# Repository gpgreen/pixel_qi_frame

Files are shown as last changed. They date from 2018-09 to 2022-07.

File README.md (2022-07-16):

# Pixel Qi Frame

3D printed frame for [Pixel Qi](https://www.adafruit.com/product/1303)
LCD panel. Includes adafruit hdmi [LVDS display driver
board](https://cdn-shop.adafruit.com/datasheets/PCB800099.pdf).  The
frame was modeled in OpenScad and is fully parametric. Conceivably it
can accomodate other types of LCD panels, with proper adjustment of
the parameters.

## OpenScad main file
display_frame.scad

## Included files
1. frameconfig.scad
2. button.scad
3. frame.scad
4. graphics_box.scad

## Pictures of printed frame

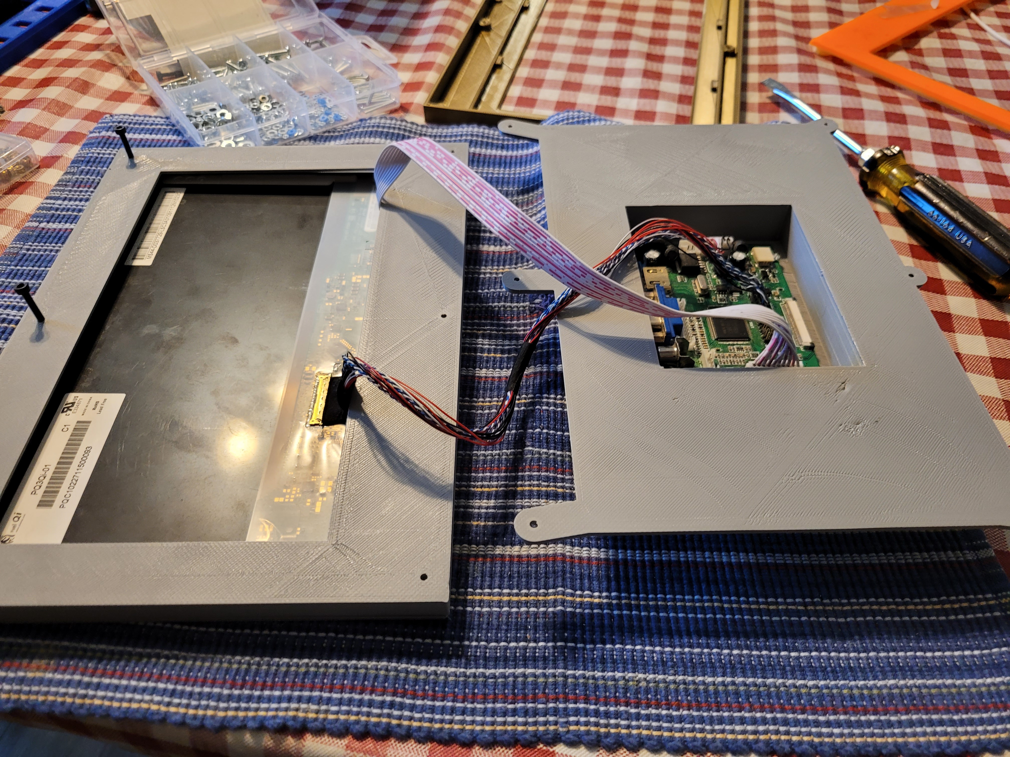
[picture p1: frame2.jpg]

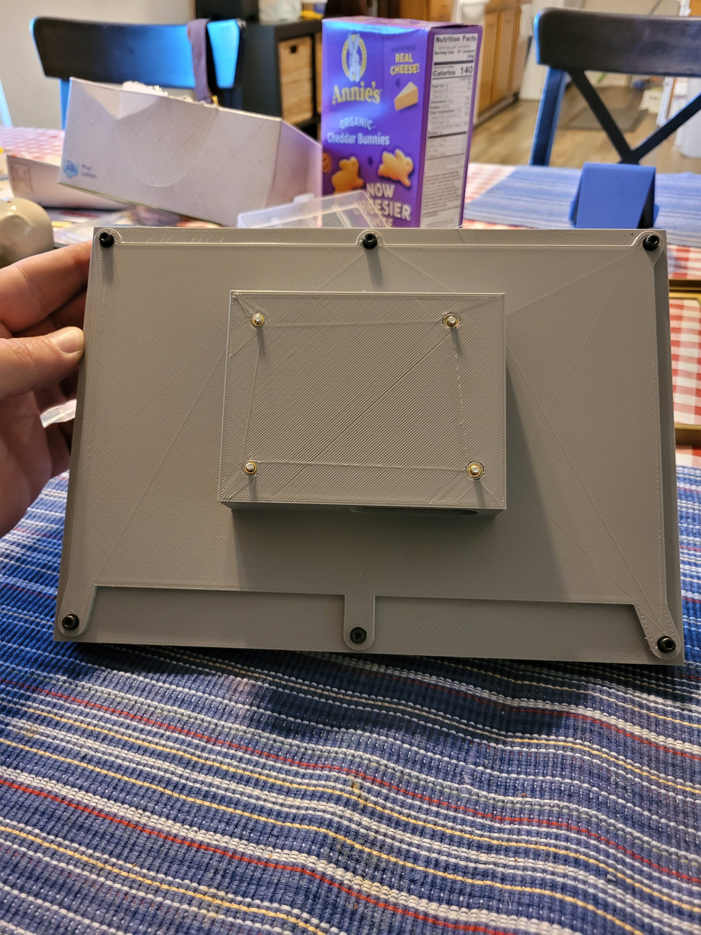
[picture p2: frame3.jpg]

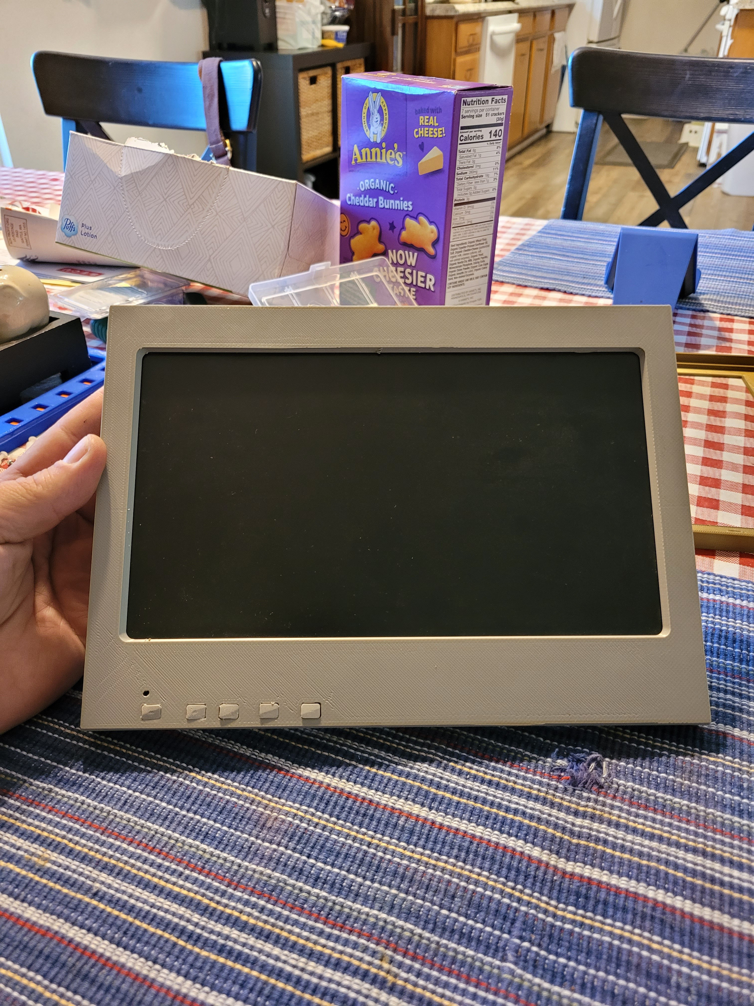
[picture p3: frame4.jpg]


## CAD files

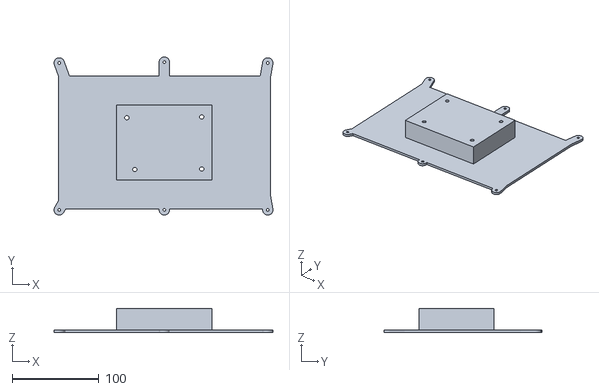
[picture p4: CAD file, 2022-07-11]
graphics_box.stl
252.0 x 182.0 x 28.0

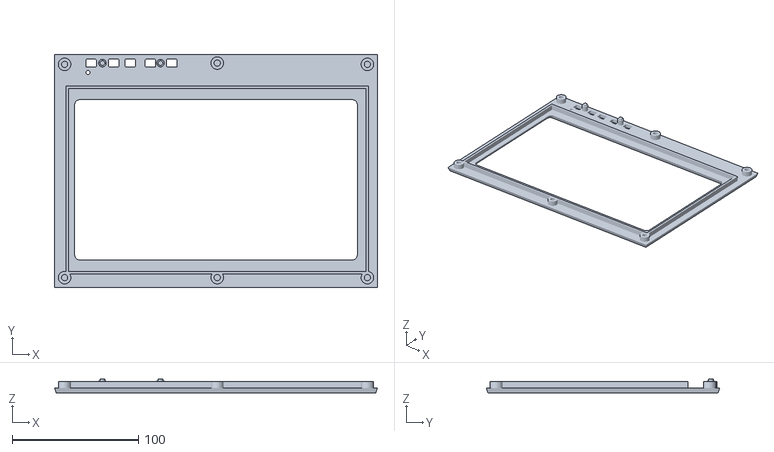
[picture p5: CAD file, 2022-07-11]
front_frame.stl
256.0 x 185.0 x 11.0

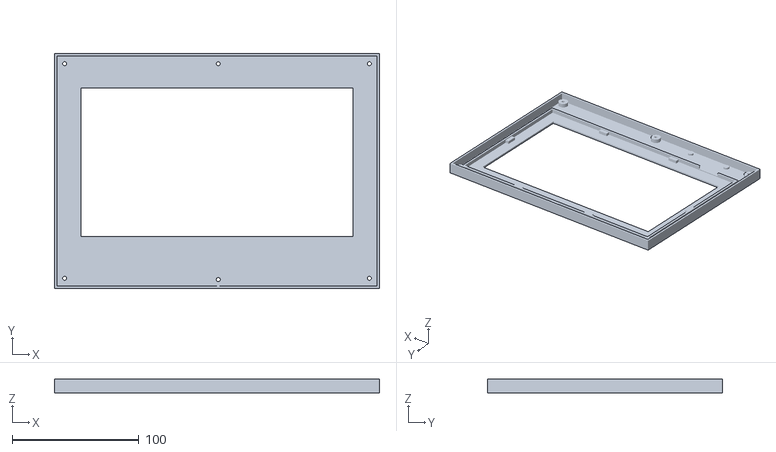
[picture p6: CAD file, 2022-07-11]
back_frame.stl
256.0 x 185.0 x 11.0

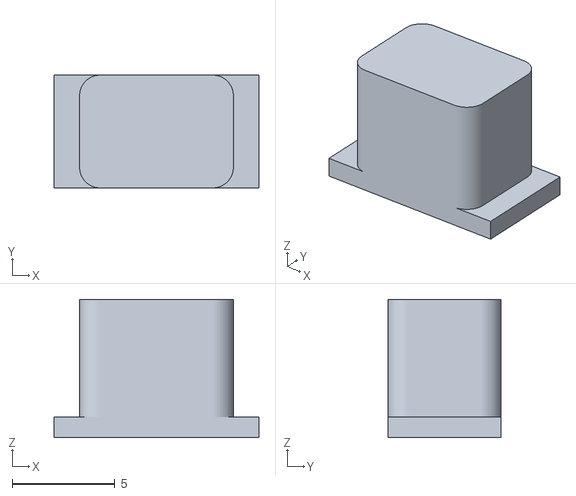
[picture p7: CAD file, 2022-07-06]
bot_button.stl
10.0 x 5.50 x 6.75

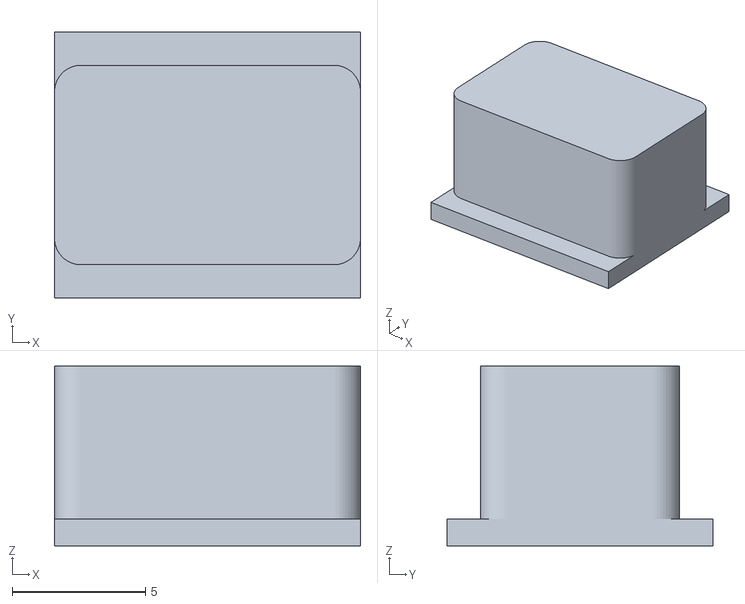
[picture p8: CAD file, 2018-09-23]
side_button.stl
11.5 x 10.0 x 6.75

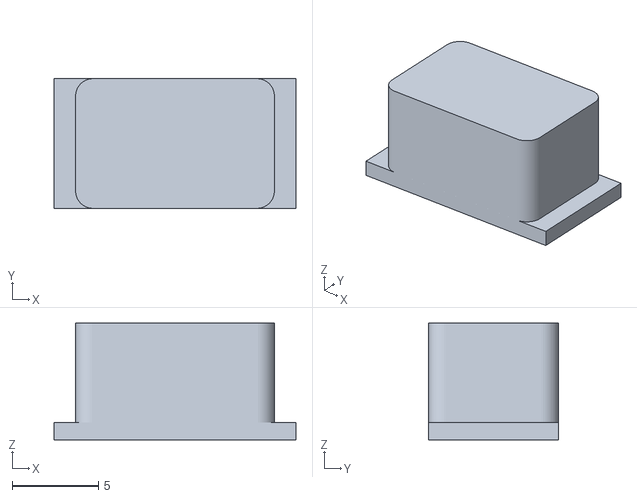
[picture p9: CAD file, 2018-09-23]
bottom_button.stl
14.0 x 7.50 x 6.75

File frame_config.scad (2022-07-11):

// Display for Pixel Qi lcd panel
// Copyright 2022 Greg Green
//
// frame_config.scad

// configurations
have_side_buttons=0;
have_bottom_buttons=1;
have_led_hole=1;
have_connector_holes=0;
have_display_buttons=1;
show_pcbs=1;

// display
display_width=234;
display_height=143;
// distances in from outside to viewing surface of display
display_top_bezel=8;
display_bottom_bezel=8;
display_left_bezel=4;
display_right_bezel=6;
// thickness of panel
display_thickness=6;

// flange inside frame
flange_height=5;
flange_gap=1;
flange_width=2;

// faceplate
faceplate_inset=2;
faceplate_lside_width=(have_side_buttons==1)? 22 : 12;
faceplate_rside_width=(have_side_buttons==1)? 20 : 10;
faceplate_top_width=14;
faceplate_bottom_width=(have_bottom_buttons==1)? 28 : 10;
faceplate_thickness=4;

// backframe
backframe_thickness=11;
backframe_center_thickness=2;
backframe_inset=5;

// side button placement
side_button_y_offsets = [-48, -24, 0, 24, 48];
side_button_pcb_offsets = [60,36,12,-12,-36,-60];

// bottom button placement
bottom_button_x_offsets = [-100, -82, -69, -53, -36];
bottom_button_pcb_offsets = [-91, -45];
bottom_connector_x = -20;

button_width=6;
button_height=4;
button_thickness=faceplate_thickness+2;
button_radius=1;
// center of button offset from outer frame edge
button_bottom_offset=5;
// inner edge of button offset from inner frame edge
button_side_offset=5;

// lcd panel pcb bosses
pcb_boss_radius=1.9;
pcb_thickness=1.5;

button_boss_radius=3;
button_boss_height=5.5;

backframe_boss_radius=3;
backframe_boss_height=backframe_thickness-pcb_thickness-button_boss_height;

// frame holes
frame_hole_radius = 1.6;
frame_hole_insert_radius = 2.5;
frame_boss_radius = 5;

// led coord
led_placement = [-102.5,7.5];
led_radius = 1.6;

// graphics board
graphics_box_height = 28;
graphics_box_thickness = 3;
graphics_pcb_offset = 10;

// graphics board pcb constants
graphics_pcb_width = 90;
graphics_pcb_height = 66;
graphics_pcb_thickness = 1.5;

graphics_pcb_hole_radius = 1.6;
graphics_pcb_insert_radius = 2.5;
graphics_pcb_coords = [
     [11,2], [88,2.5], [88,62.5], [1.8,61.5]
];

graphics_pcb_boss_height = 5;
graphics_pcb_boss_radius = 4;

//////////////////////////////////////////////////////////////////////////////////////////////////////////////
// derived variables
//////////////////////////////////////////////////////////////////////////////////////////////////////////////

// Vector of display corners
display_corners = [
    [-display_width/2-faceplate_lside_width,-display_height/2-faceplate_bottom_width,0],
    [-display_width/2-faceplate_lside_width,display_height/2+faceplate_top_width,0],
    [display_width/2+faceplate_rside_width,display_height/2+faceplate_top_width,0],
    [display_width/2+faceplate_rside_width,-display_height/2-faceplate_bottom_width,0]
];

// center lines of buttons
center_left_button_x = -display_width/2-faceplate_lside_width+button_side_offset+button_width/2;
center_right_button_x = display_width/2+faceplate_lside_width-button_side_offset-button_width/2;
center_bottom_button_y = -display_height/2-faceplate_bottom_width+button_bottom_offset+button_height/2;

// vector of frame bolt hole centers
bolt_offset = frame_boss_radius+3; // how far to offset from edge of display
bolt_displ = display_corners + [
     [bolt_offset, bolt_offset],
     [bolt_offset,-bolt_offset],
     [-bolt_offset,-bolt_offset],
     [-bolt_offset,bolt_offset]
];
bolt_hole_centers = concat(bolt_displ, [[0, bolt_displ[2].y]], [[0, center_bottom_button_y]]);

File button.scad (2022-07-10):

// Display from for Pixel Qi lcd panel
// Copyright 2022 Greg Green
//
// button.scad

include <frame_config.scad>

module button_top() {
    minkowski() {
        cube([button_width-button_radius*.5,
        button_height-button_radius*.5,
        button_thickness-2],
        center=true);
        cylinder(r=button_radius, h=1, $fn=64);
    }
}

module button_bottom() {
    linear_extrude(height=1, center=true) {
        polygon(points=[
	[-1, -.75],
	[button_width+3,-.75],
	[button_width+3, button_height+.75],
	[-1, button_height+.75],
	[-1,-.75]]);
    }
}

module side_button_bottom() {
    linear_extrude(height=1, center=true) {
        polygon(points=[
	[-.75, -1],
	[button_width+.75,-1],
	[button_width+.75, button_height+3],
	[-.75, button_height+3],
	[-.75,-1]]);
    }
}

module bottom_button() {
    translate([-button_width/2-1,-button_height/2,0.5])
        button_bottom();
    translate([0,0,button_thickness/2])
        button_top();
}

module side_button() {
    translate([-button_width/2,-button_height/2-1,0.5])
        side_button_bottom();
    translate([0,0,button_thickness/2])
        button_top();
}

module side_buttons() {
    for(y = side_button_y_offsets) {
        translate([center_left_button_x,y,-1])
            side_button();
	    translate([center_right_button_x,y,-1])
	        side_button();
    }
}

module bottom_buttons() {
    for(x=bottom_button_x_offsets) {
        translate([x,center_bottom_button_y,-1])
            bottom_button();
    }
}

side_buttons();
bottom_buttons();

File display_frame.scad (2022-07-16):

// Display for Pixel Qi lcd panel
// Copyright 2022 Greg Green
//
// display_frame.scad

include <frame_config.scad>
use <frame.scad>
use <button.scad>
use <graphics_box.scad>

mod = "display";
do_quarter_cut = false;

if (mod == "display") {
     back_frame();
     front_frame();
     graphics_box_assy();
     if (have_side_buttons==1) side_buttons();
     if (have_bottom_buttons==1) bottom_buttons();
     if (show_pcbs==1) graphics_pcb();
}
else if (mod == "display_cut") {
     difference() {
          union() {
               back_frame();
               front_frame();
               graphics_box_assy();
               if (have_side_buttons==1) side_buttons();
               if (have_bottom_buttons==1) bottom_buttons();
               if (show_pcbs==1) graphics_pcb();
          }
          translate([-display_width/2-faceplate_lside_width-10,-100-display_height/2-faceplate_bottom_width+7,-50])
               cube([display_width+50,100,100]);
     }
}
else if (mod == "front_frame") {
     translate([0,0,faceplate_thickness])
          rotate([180,0,0])
          if (do_quarter_cut) {
               front_frame_left();
               front_frame_right();
               front_frame_top();
               front_frame_bottom();
          }
          else
               front_frame();
}
else if (mod == "back_frame") {
     translate([0,0,backframe_thickness])
          if (do_quarter_cut) {
               back_frame_left();
               back_frame_right();
               back_frame_top();
               back_frame_bottom();
          }
          else
               back_frame();
}
else if (mod == "bottom_button") {
     bottom_button();
}
else if (mod == "side_button") {
     side_button();
}
else if (mod == "graphics_box") {
     translate([0,0,-backframe_thickness])
          rotate([180,0,0])
          graphics_box_assy();
}
else if (mod == "front_frame_left")
     front_frame_left();
else if (mod == "front_frame_right")
     front_frame_right();
else if (mod == "front_frame_top")
     front_frame_top();
else if (mod == "front_frame_bottom")
     front_frame_bottom();
else if (mod == "back_frame_left")
     back_frame_left();
else if (mod == "back_frame_right")
     back_frame_right();
else if (mod == "back_frame_bottom")
     back_frame_bottom();
else if (mod == "back_frame_top")
     back_frame_top();

/////////////////////////////////////////////////////////////////////////////
// cutting the frame for a small printer
/////////////////////////////////////////////////////////////////////////////
fcut_line = [
     [4,faceplate_thickness+.5],
     [4,faceplate_thickness-2],
     [2,faceplate_thickness-2],
     [2,faceplate_thickness-1],
     [-1,faceplate_thickness-1],
     [-1,-3],
     [-3,-3],
     [-3,-2],
     [-5,-2],
     [-5,-backframe_thickness+2]];

cut_gap=.2;

module front_cutoff_bottom() {
     fcut_offset=[
          [-cut_gap,0],
          [-cut_gap,cut_gap],
          [cut_gap,cut_gap],
          [cut_gap,cut_gap],
          [-cut_gap,cut_gap],
          [-cut_gap,cut_gap],
          [cut_gap,cut_gap],
          [cut_gap,cut_gap],
          [-cut_gap,cut_gap],
          [-cut_gap,0]];
     outline = concat(fcut_line+fcut_offset,
                      [[display_width,-backframe_thickness+2],
                       [display_width,faceplate_thickness],
                       [4-cut_gap,faceplate_thickness+.5]]);
     rotate(a=[90,0,0])
          linear_extrude(height=display_height*2, center=true)
          polygon(outline);
}

module front_cutoff_top() {
     outline = concat(fcut_line,
                      [[-display_width,-backframe_thickness+2],
                       [-display_width,faceplate_thickness],
                       [4,faceplate_thickness+.5]]);
     rotate(a=[90,0,0])
          linear_extrude(height=display_height*2, center=true)
          polygon(outline);
}

module front_frame_left() {
     translate([-10,0,0])
          rotate(a=[180,0,0])
          difference() {
          front_frame();
          translate([-70,0,0])
               front_cutoff_bottom();
     }
}

module front_frame_bottom() {
     translate([0,30,0])
          rotate(a=[180,0,0])
          difference() {
          front_frame();
          translate([-70,0,0])
               front_cutoff_top();
          translate([70,0,0])
               rotate(a=[0,0,180])
               front_cutoff_top();
          translate([-75,0,-75])
               cube([150,150,150]);
     }
}

module front_frame_top() {
     translate([0,-20,0])
          rotate(a=[180,0,0])
          difference() {
          front_frame();
          translate([-70,0,0])
               front_cutoff_top();
          translate([70,0,0])
               rotate(a=[0,0,180])
               front_cutoff_top();
          translate([-75,-150,-75])
               cube([150,150,150]);
     }
}

module front_frame_right() {
     translate([10,0,0])
          rotate(a=[180,0,0])
          difference() {
          front_frame();
          translate([70,0,0])
               rotate(a=[0,0,180])
               front_cutoff_bottom();
     }
}

bcut_line = [
     [4,-backframe_thickness-1],
     [4,-backframe_thickness+1],
     [0,-backframe_thickness+1],
     [0,-3],
     [-2,-3],
     [-2,-4],
     [-4,-4],
     [-4,0]];

module back_cutoff_top() {
     outline = concat(bcut_line,
                      [[display_width,0],
                       [display_width,-backframe_thickness-1],
                       [4,-backframe_thickness-1]]);
     rotate(a=[90,0,0])
          linear_extrude(height=display_height*2, center=true)
          polygon(outline);
}

module back_cutoff_bottom() {
     bcut_offset = [
          [cut_gap,0],
          [cut_gap,cut_gap],
          [cut_gap,cut_gap],
          [cut_gap,cut_gap],
          [-cut_gap,cut_gap],
          [-cut_gap,cut_gap],
          [cut_gap,cut_gap],
          [cut_gap,0]];
     outline = concat(bcut_line + bcut_offset,
                      [[-display_width,0],
                       [-display_width,-backframe_thickness-1],
                       [4+cut_gap,-backframe_thickness-1]]);
     rotate(a=[90,0,0])
          linear_extrude(height=display_height*2, center=true)
          polygon(outline);
}

module back_frame_left() {
     difference() {
          back_frame();
          translate([-80,0,0])
               back_cutoff_top();
     }
}

module back_frame_right() {
     difference() {
          back_frame();
          translate([80,0,0])
               rotate(a=[0,0,180])
               back_cutoff_top();
     }
}

module back_frame_bottom() {
     translate([0,-30,0])
          difference() {
          back_frame();
          translate([-80,0,0])
               back_cutoff_bottom();
          translate([80,0,0])
               rotate(a=[0,0,180])
               back_cutoff_bottom();
          translate([-90,0,-90])
               cube([180,180,180]);
     }
}

module back_frame_top() {
     translate([0,20,0])
          difference() {
          back_frame();
          translate([-80,0,0])
               back_cutoff_bottom();
          translate([80,0,0])
               rotate(a=[0,0,180])
               back_cutoff_bottom();
          translate([-90,-180,-90])
               cube([180,180,180]);
     }
}

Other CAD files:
frame.scad
graphics_box.scad

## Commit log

2018-08-13 Added button holes
    [frame.scad]
2018-08-14 Added bottom frame
    [frame.scad]
2018-08-14 Fixed backframe
    [frame.scad]
2018-08-15 first draft
    [frame.scad, front_frame_left.stl]
2018-08-17 First try with new design
    [frame.scad, front_frame_left.stl, front_frame_right.stl]
2018-08-19 Added buttons and print files
    [back_frame_left.stl, back_frame_right.stl, button.scad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]
2018-08-30 Updated buttons
    New splits on frames
    They are now each in 4 pieces
    [button.scad, display_frame.scad, frame.scad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]
2018-09-04 Revamped back frame split
    [display_frame.scad]
2018-09-23 Updated front frame cutplanes and pcb boss
    [back_frame_bottom.stl, back_frame_left.stl, back_frame_right.stl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]
2018-09-24 Added connector holes in back frame
    [back_frame_bottom.stl, back_frame_left.stl, back_frame_right.stl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]
2018-09-29 Fixed pcb thickness, adjusted related elements
    [frame.scad, frame_config.scad]
2018-10-01 Fixed back frame flange
    [back_frame_bottom.stl, back_frame_left.stl, back_frame_right.stl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]
2018-12-10 Added frame hole
    [back_frame_bottom.stl, back_frame_left.stl, back_frame_right.stl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]
2020-12-17 added have_buttons config option
    fixed frame to use config
    [display_frame.scad, frame.scad, frame_config.scad]
2022-07-03 Added more options
    instead of 'have_buttons', added 'have_side_buttons' and
    'have_bottom_buttons'
    Also added 'have_connector_holes' option
    Increased bottom width to accomodate pcb board
    bottom buttons and pcb bosses are placed with vectors instead of evenly spaced
    this is done with the vars 'bottom_button_x_offsets' and
    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
    [button.scad, display_frame.scad, frame.scad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]
2022-07-06 first rendition of graphics_box
    [button.scad, display_frame.scad, frame.scad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]
2022-07-06 Fixed lcd panel locations
    Added connector hole to graphic_box
    [back_frame.stl, bot_button.stl, display_frame.scad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]
2022-07-07 upper hole bosses interfere with display
    made flanges wider
    changed all vars with _rad to _radius
    added config variable have_display_buttons and show_pcbs
    added pads on back frame to hold pixel qi against front frame
    more derived variables
    [back_frame.stl, button.scad, display_frame.scad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]
2022-07-09 checkpoint for test print
    [back_frame_bottom.stl, back_frame_left.stl, back_frame_right.stl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]
2022-07-10 fixed led hole location
    [frame.scad, frame_config.scad]
2022-07-10 Removed number of side buttons
    using vectors for placement of side buttons, like on bottom
    [button.scad, display_frame.scad, frame.scad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]
2022-07-11 Reexported front and back frame
    [back_frame.stl, display_frame.scad, frame_config.scad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]
2022-07-11 Updated graphics_box to bolt using frame bolts
    [display_frame.scad, graphics_box.scad, graphics_box.stl]
2022-07-16 Added README.md
    Moved frame cutting to end of display_frame.scad file
    [display_frame.scad]
